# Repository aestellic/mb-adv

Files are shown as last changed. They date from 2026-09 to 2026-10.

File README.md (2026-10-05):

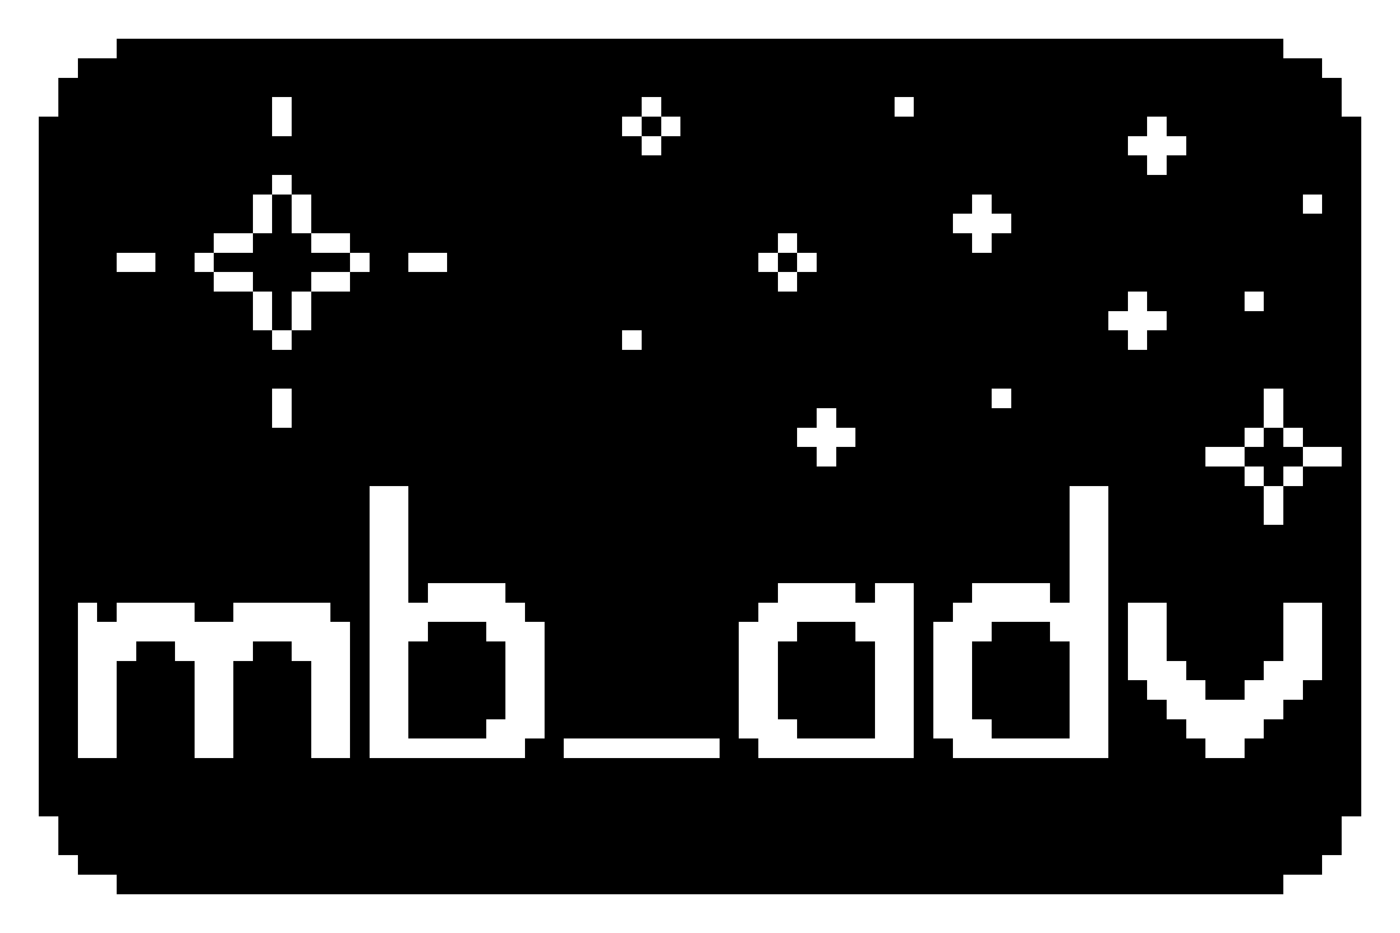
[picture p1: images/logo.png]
# 

> [!WARNING]
> This project (and its associated firmware) is a work-in-progress and is currently incomplete.

The mb_adv is a dongle for your GBA which injects multiboot ROMs via link cable.

With it, you can do stuff like [shiny hunt Jirachi without being tethered to a Gamecube](https://bsky.app/profile/cozydelaney.standingintheodds.com/post/3mt42ccd4bk23), boot [Poké Transporter GB](https://github.com/Striaton-Lab-Team/Poke_Transporter_GB), and even [connect your GBA to the internet](https://gblink.io/)!

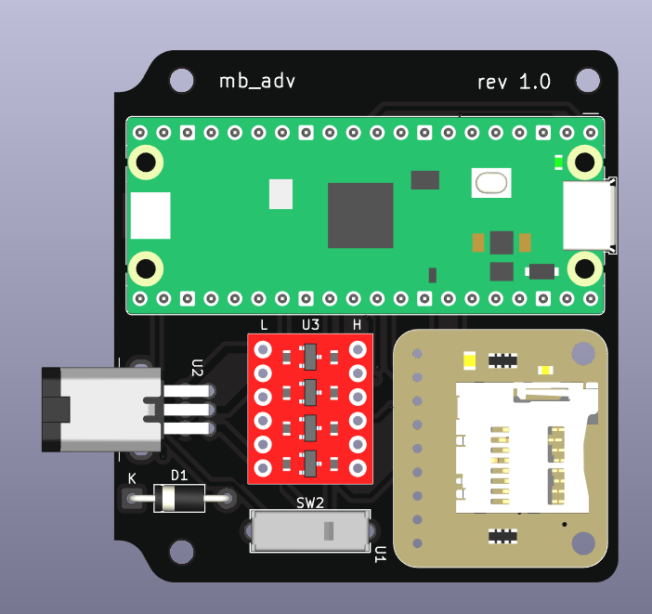
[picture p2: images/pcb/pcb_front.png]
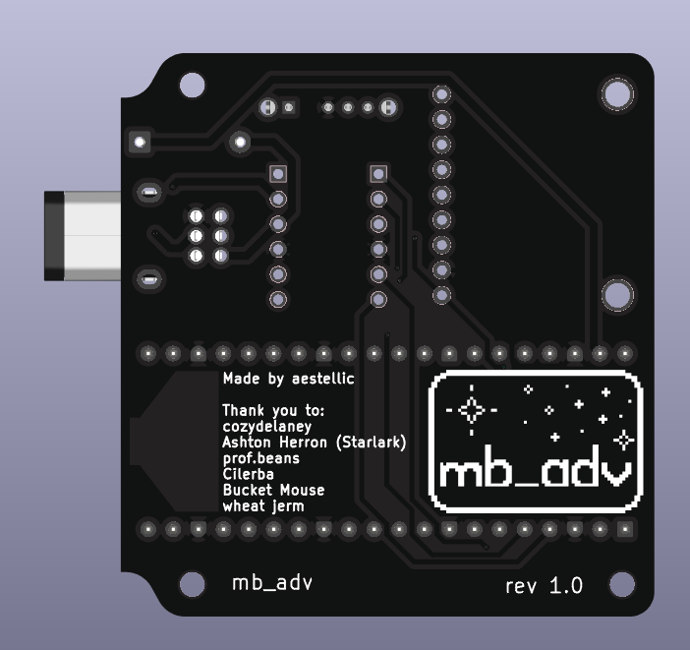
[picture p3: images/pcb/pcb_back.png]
 

If you'd like to buy one and are located in the USA, you can visit my store here (link will be added when store goes live). Otherwise, please see [MANUFACTURING.md](MANUFACTURING.md) for how to build one yourself!

# Usage
W.I.P

# F.A.Q.
How does this differ from the GB-Link?

- While the GB-Link needs to be connected to a computer/phone to work, the mb_adv draws power directly from the GBA. This lets the mb_adv work without plugging into any external devices!

What does mb_adv stand for?

- It stands for multiboot advance.

What the heck is a multiboot?

- It's a small GBA program that can be sent over the link cable. This is the same system that multiplayer games which only required one cartridge use. It's also used for a lot of Pokémon distributions!

How did you make this?

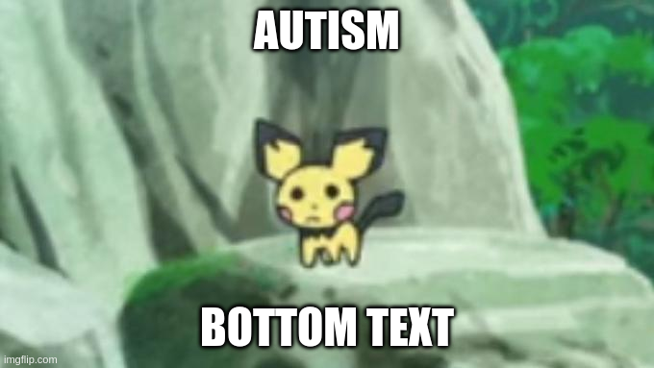
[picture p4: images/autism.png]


# Credits
This project would not have been possible without the following people:
- [cozydelaney](https://bsky.app/profile/cozydelaney.standingintheodds.com), who designed the logo and provided so much emotional support <3
- [Ashton Herron (Starlark)](https://github.com/starlarkus), who guided me through the planning stages of the mb_adv.
- [prof.beans](https://www.thebeanlabs.com/), who designed the enclosure for the mb_adv.
- [Bucket Mouse](https://github.com/MouseBiteLabs), who helped with choosing components and designing the schematic and PCB.
- wheat jerm, who helped with designing the schematic and PCB.
- [The GB-Link Team](https://gblink.io/), who created the incredible GB-Link and [GB-Link firmware](https://github.com/GB-Link/GBLink-Firmware).
- [loopj](https://github.com/loopj/gba-link-port), who created the footprint and 3D model for the male GBA link cable connector.
- [zaksabeast](https://github.com/zaksabeast/Portable-Pico-Multibooter), who served as the inspiration and foundation for this project
> Note: the mb_adv is not endorsed by zaksabeast in any way, shape, or form.

# License
This project is fully open sourced under the [MIT License](LICENSE).

# Technical References
See [MANUFACTURING.md](MANUFACTURING.md) and [SCHEMATIC.pdf](SCHEMATIC.pdf)

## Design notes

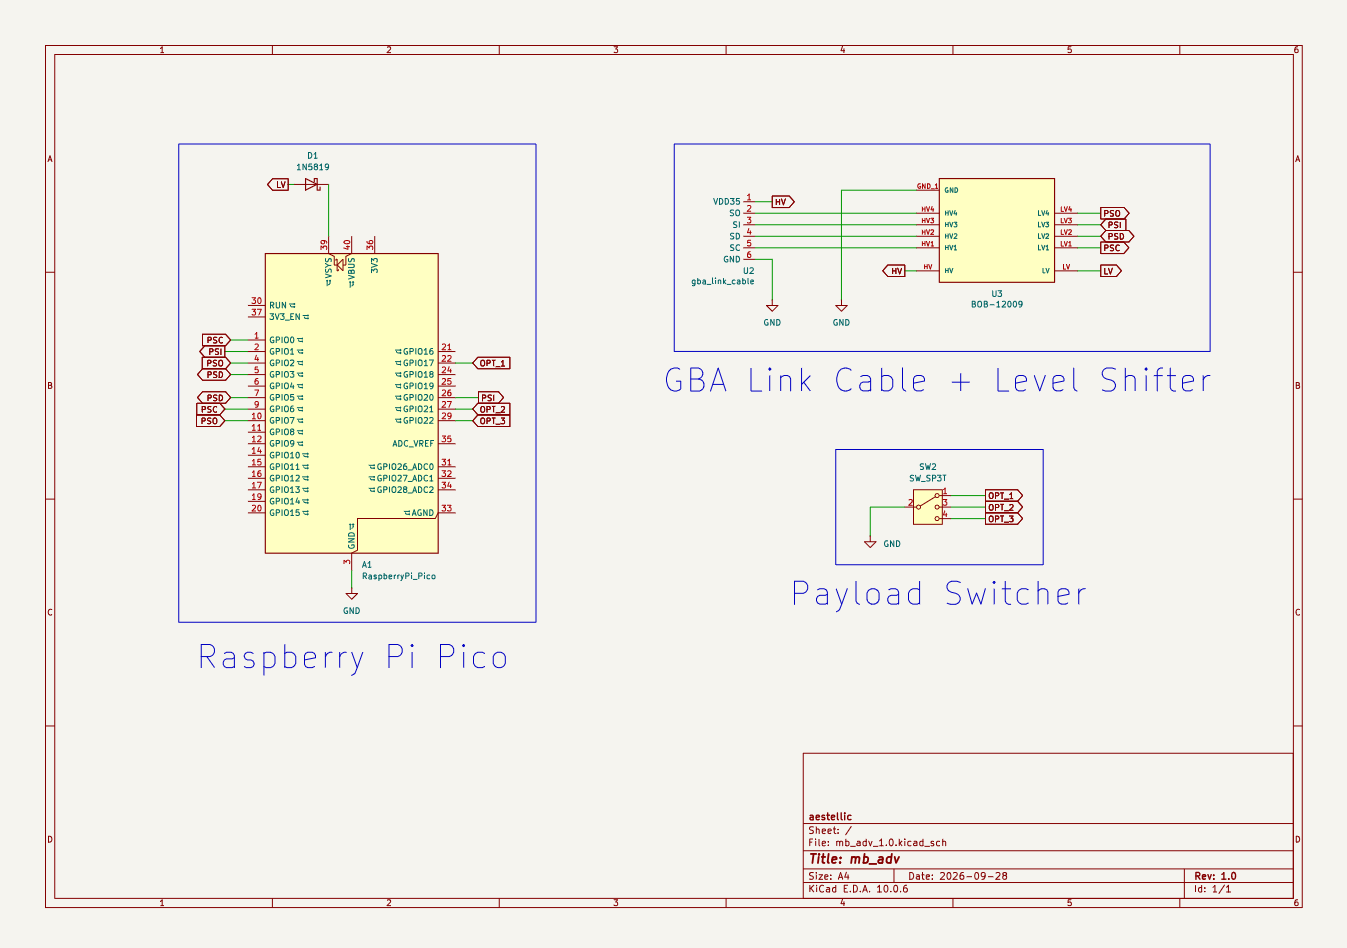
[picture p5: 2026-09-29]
images/pcb/schematic.png

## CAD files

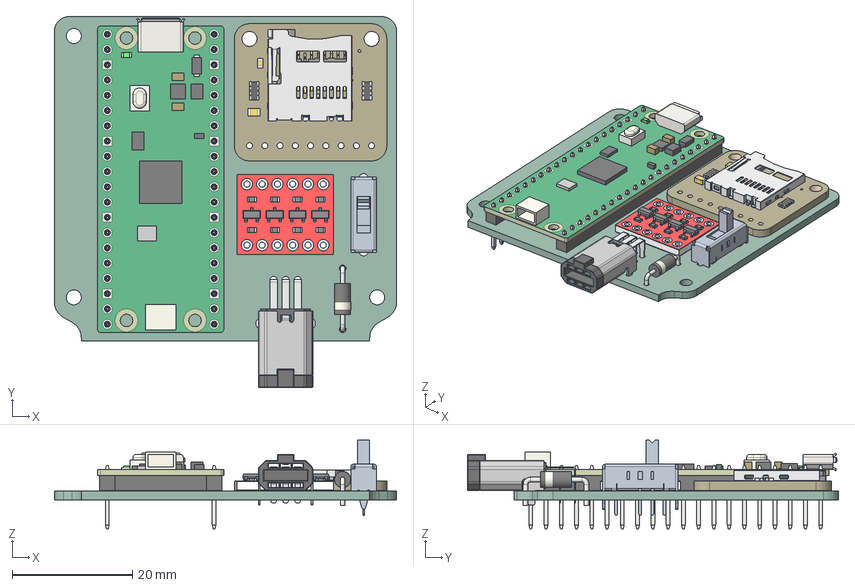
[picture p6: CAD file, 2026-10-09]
mb_adv_1.0.step
57.0 x 61.8 x 14.8 mm
Board
MICROSD
0805-NO
0603-NO
RESPACK_4X0603 x 2
Plastic Insert
Pin Long x 3
Pin Short x 3
BOB-12009
OS-103011MS8QP1_SW0001_PRT
D_DO-41_SOD81_P10.16mm_Horizontal
RaspberryPi_Pico_H_Module_KiCad
RaspberryPi_Pico_Header_DIP-40_H2.54mm_KiCad
mb_adv_1.0_PCB

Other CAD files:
mb_adv_1.0.stl

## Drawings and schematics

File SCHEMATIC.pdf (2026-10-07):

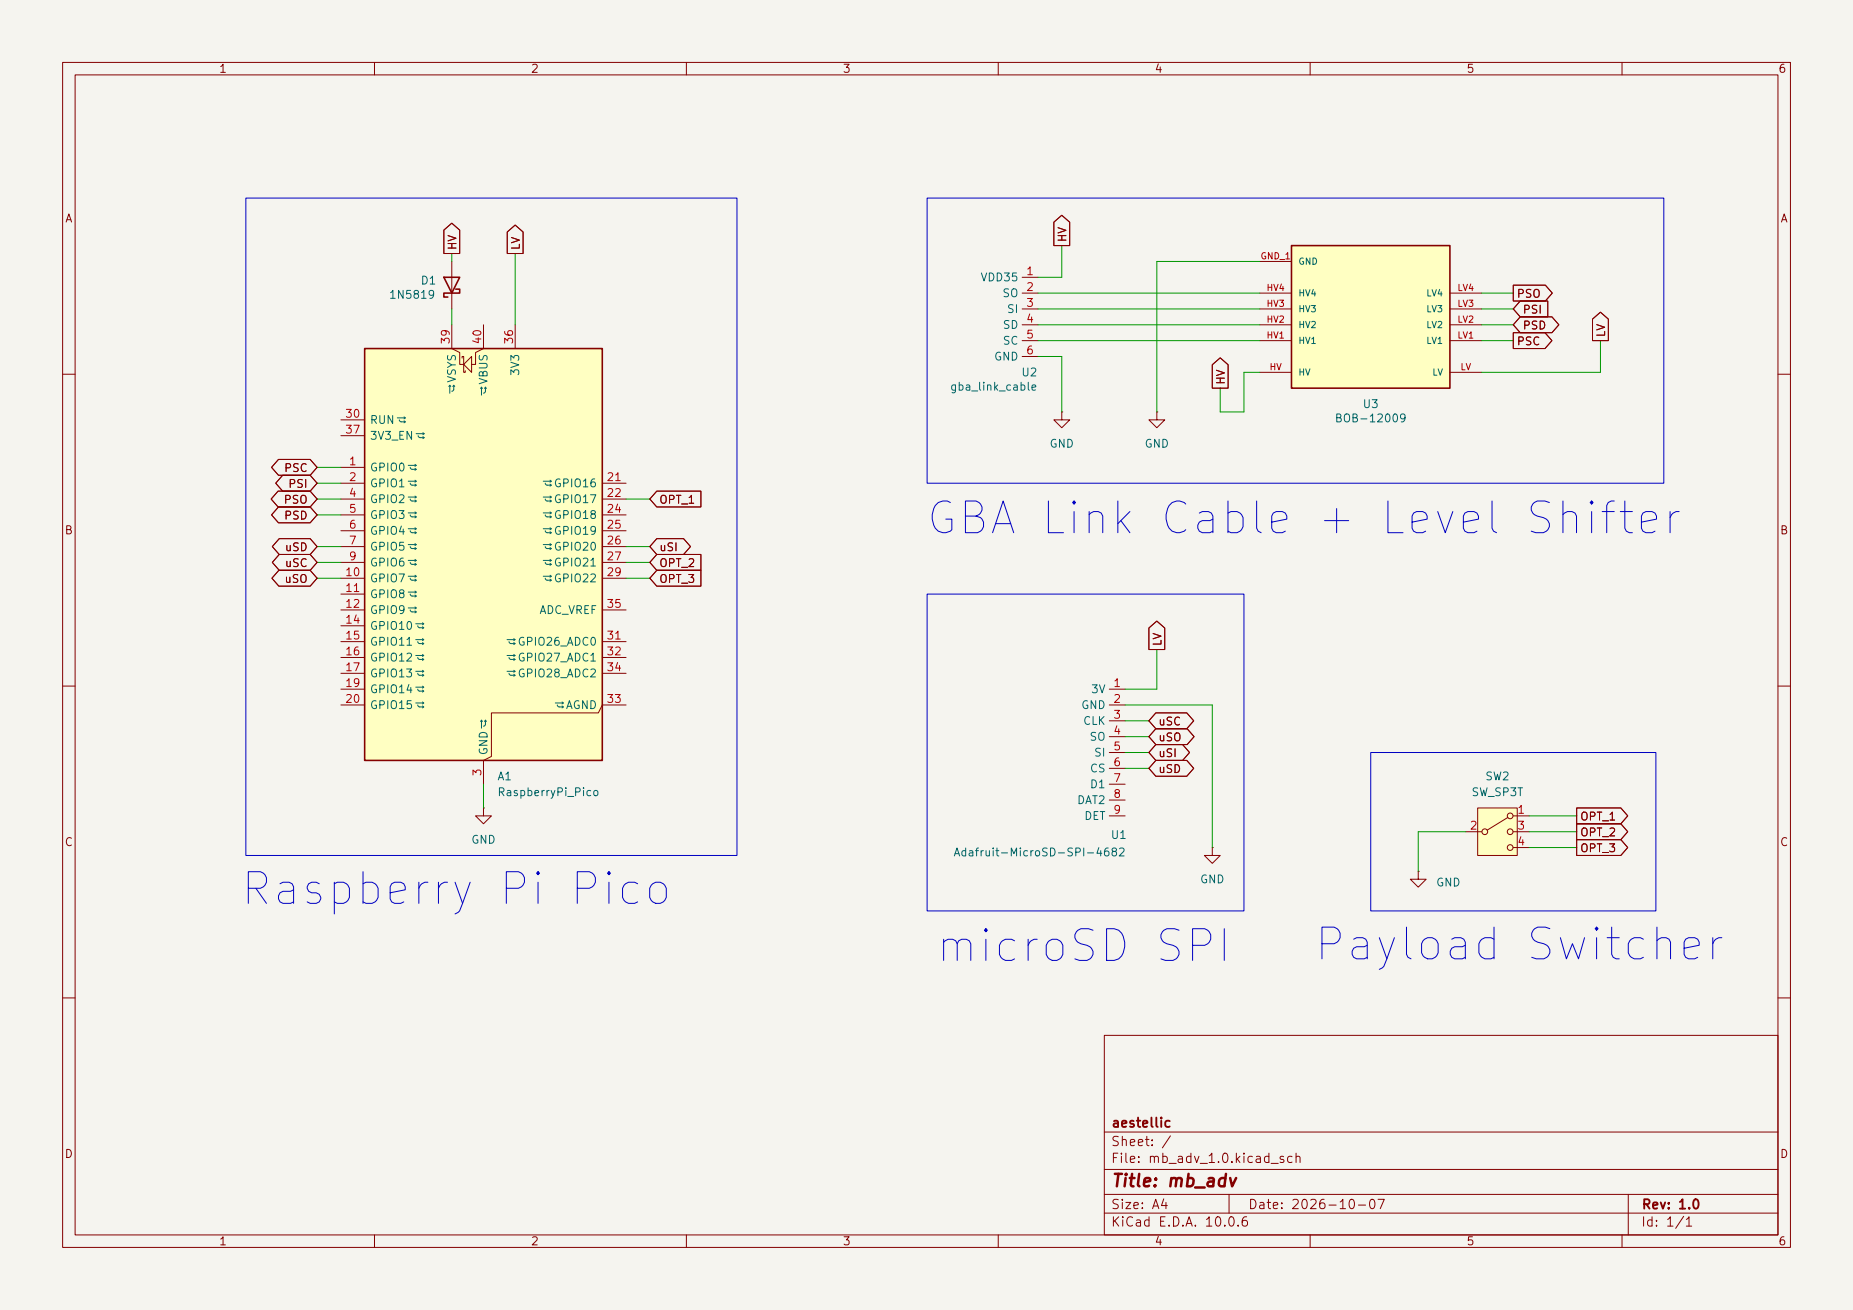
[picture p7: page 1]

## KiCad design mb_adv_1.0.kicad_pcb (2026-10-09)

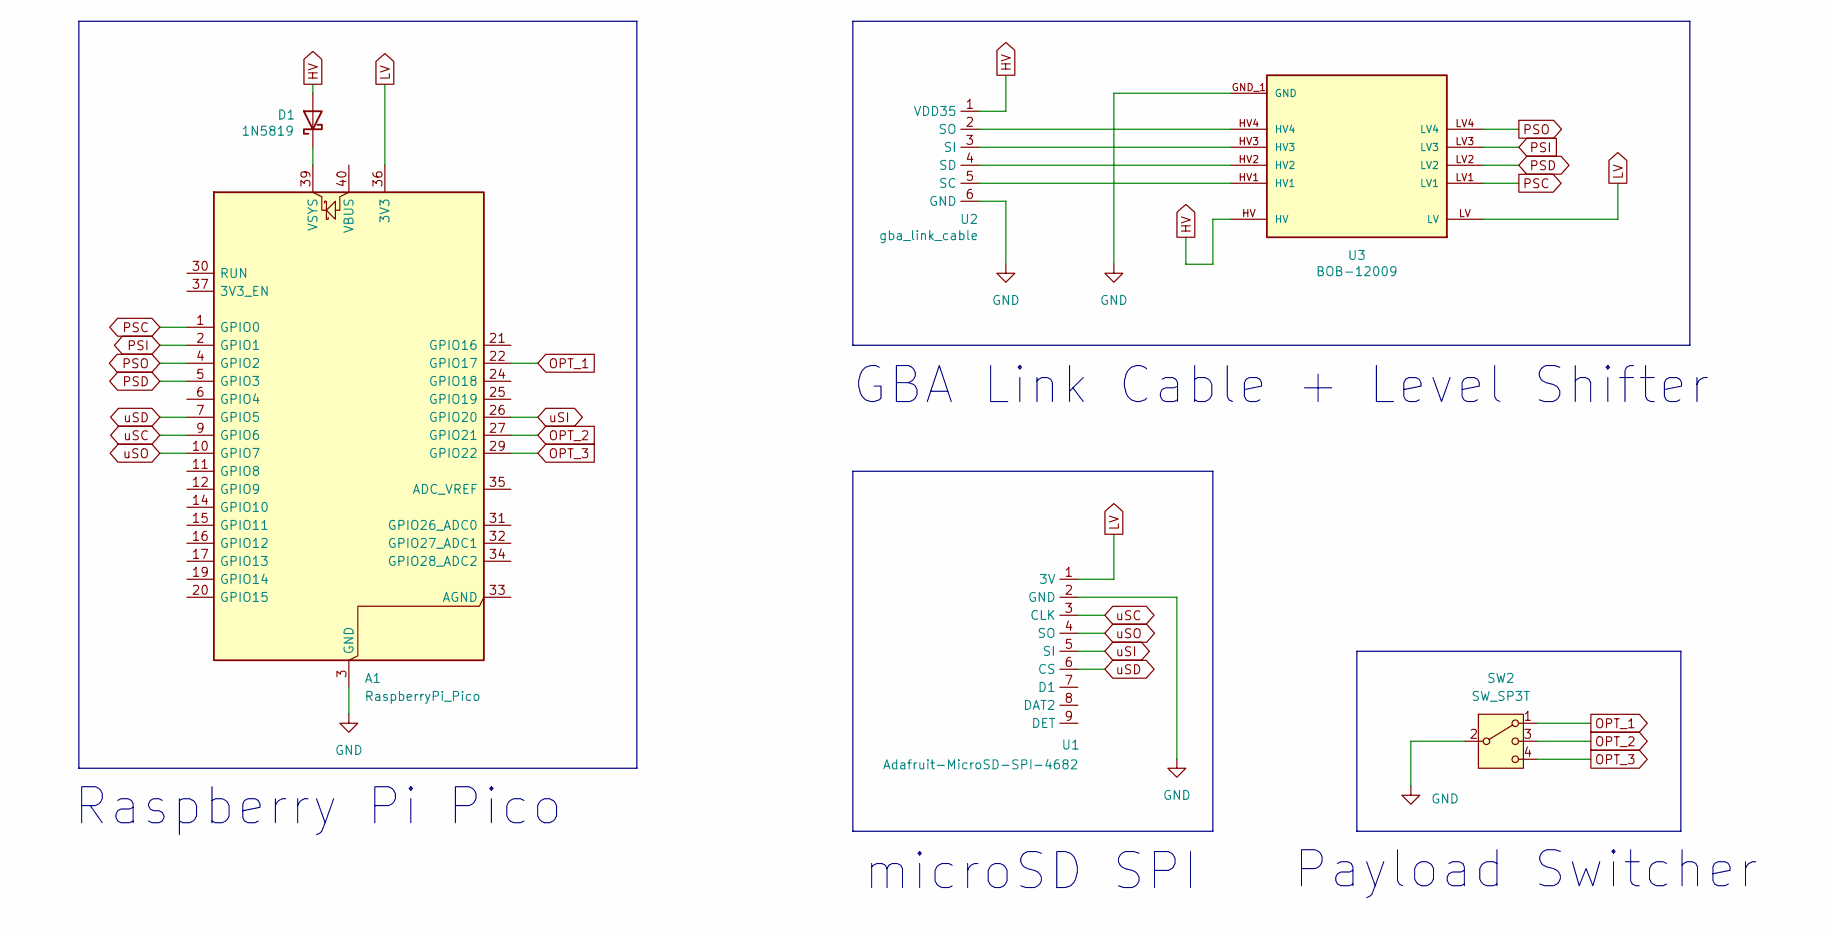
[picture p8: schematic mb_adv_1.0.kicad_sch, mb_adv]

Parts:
A1: RaspberryPi_Pico; RaspberryPi_Pico_Common_THT
D1: 1N5819; D_DO-41_SOD81_P10.16mm_Horizontal
SW2: SW_SP3T; DIP4_SP3T-TOP_4P3X8P6_CNK; MPN OS103011MS8QP1
U1: Adafruit-MicroSD-SPI-4682; adafruit_4682
U2: gba_link_cable; GBALinkPort_Male
U3: BOB-12009; CONV_BOB-12009; PARTREV 01

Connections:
GND: A1.3 (GND), A1.8 (GND), A1.13 (GND), A1.18 (GND), A1.23 (GND), A1.28 (GND), A1.38 (GND), SW2.2, U1.2 (GND), U2.6 (GND), U3.GND_1 (GND), U3.GND_2 (GND)
HV: D1.2 (A), U2.1 (VDD35), U3.HV
LV: A1.36 (3V3), U1.1 (3V), U3.LV
unnamed: A1.39 (VSYS), D1.1 (K)
unnamed: U2.5 (SC), U3.HV1
unnamed: U2.4 (SD), U3.HV2
unnamed: U2.3 (SI), U3.HV3
unnamed: U2.2 (SO), U3.HV4
OPT_1: A1.22 (GPIO17), SW2.1
OPT_2: A1.27 (GPIO21), SW2.3
OPT_3: A1.29 (GPIO22), SW2.4
PSC: A1.1 (GPIO0), U3.LV1
PSD: A1.5 (GPIO3), U3.LV2
PSI: A1.2 (GPIO1), U3.LV3
PSO: A1.4 (GPIO2), U3.LV4
uSC: A1.9 (GPIO6), U1.3 (CLK)
uSD: A1.7 (GPIO5), U1.6 (CS)
uSI: A1.26 (GPIO20), U1.5 (SI)
uSO: A1.10 (GPIO7), U1.4 (SO)

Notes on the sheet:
GBA Link Cable + Level Shifter
Payload Switcher
microSD SPI
Raspberry Pi Pico

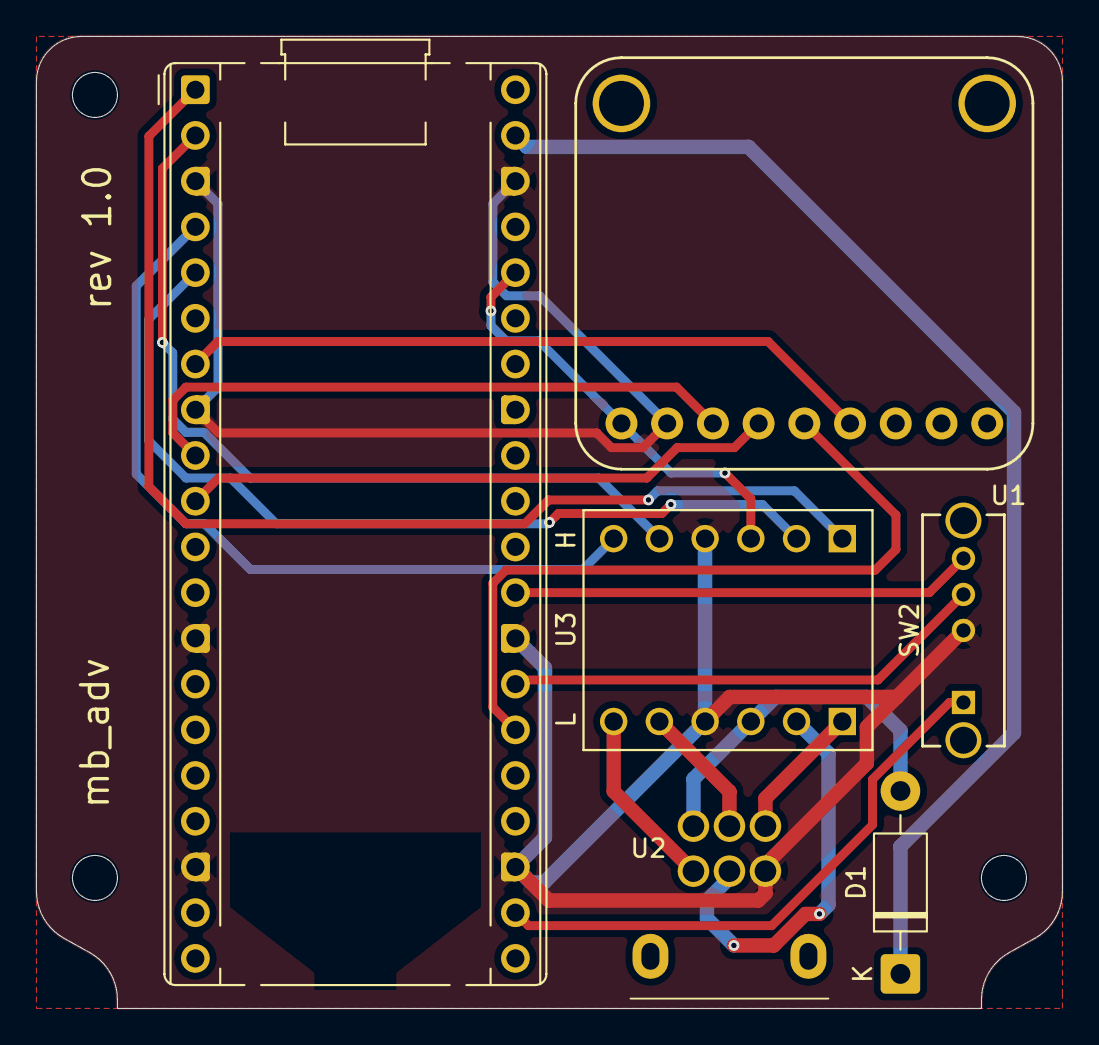
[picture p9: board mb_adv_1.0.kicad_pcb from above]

Board: 2 copper layers, 57.0 x 54.0 mm, 9 parts (0 on the bottom side), 19 nets.

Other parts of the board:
M2.5, M2.5#2, M2.5#3: MountingHole_2.5mm

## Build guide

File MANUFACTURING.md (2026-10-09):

# Manufacturing
### This is done at your own risk. I am neither suggesting nor recommending that you do this.
### These instructions do not contain any affiliate links.
1. Download GERBERS.zip
2. Go to your PCB fabricator of choice (i.e. [JLCPCB](https://cart.jlcpcb.com/quote)) and order however many PCBs you wish to make using the following settings:

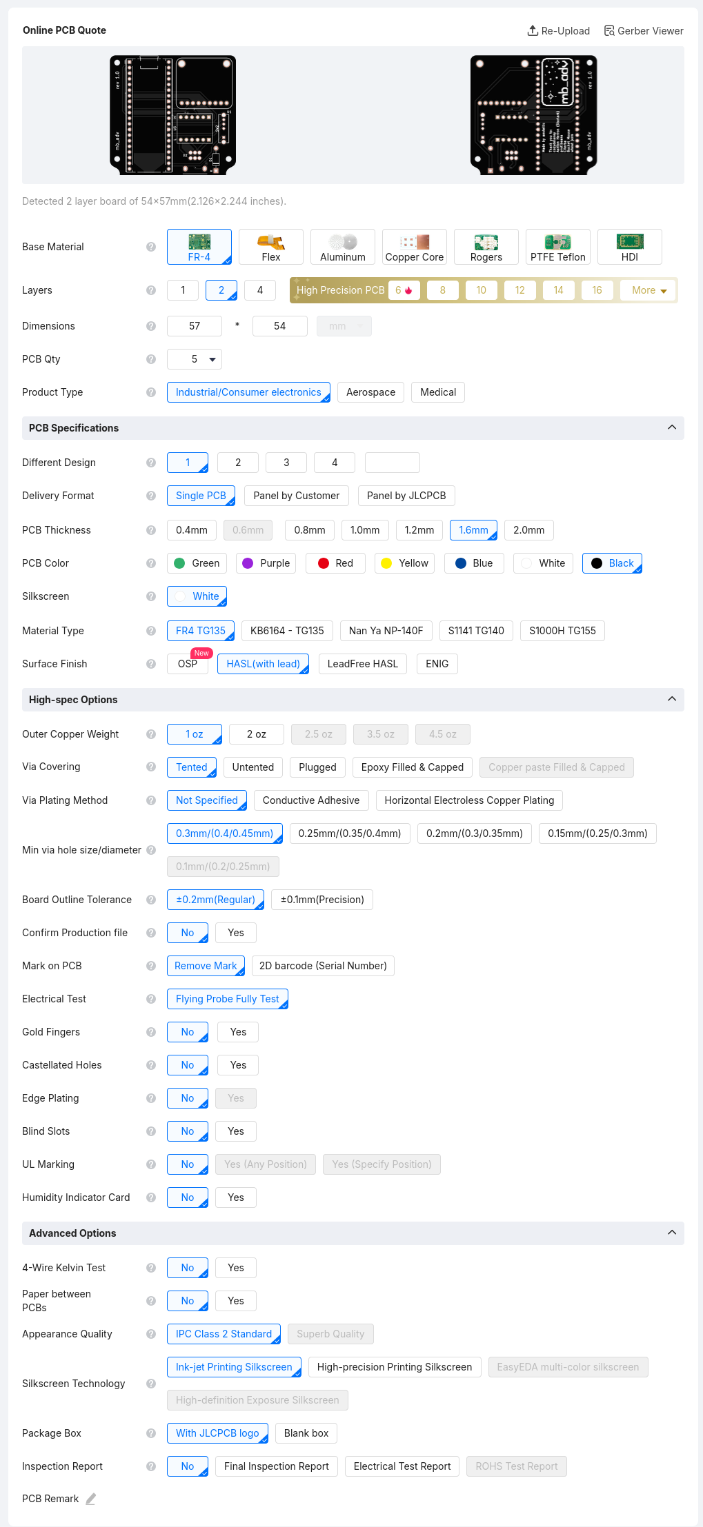
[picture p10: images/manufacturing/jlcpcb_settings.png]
JLCPCB settings


3. Choose your preferred shipping option by clicking the down arrow
> Note: JLCPCB uses ~$30 USD shippping by default. Global Standard Direct Line costs ~$7 USD and there haven't been any reports of people actually being charged the tariff in the US to my knowledge.

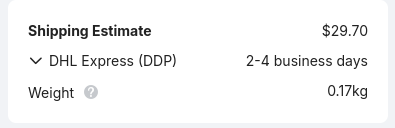
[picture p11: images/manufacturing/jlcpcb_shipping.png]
JLCPCB shipping


3.5. If you don't have access to a 3D printer, you may want to jump to step 7. Most PCB fabricators also offer 3D printing services.

4. Place your PCB (and optionally 3D printed case) order.

5. Order the following components (one per mb_adv):

|Name|Part #|Link|Notes|
|---|---|---|---|
|Raspberry Pi Pico|N/A|[4MB](https://www.aliexpress.us/item/3256808040042288.html)|Any 2MB+ Pico (including clones) which follows the official footprint is compatible with the PCB, but the buttons may not line up with the 3d printed case contained in this repo.|
|Through Hole Diode|1N5819|[DigiKey](https://www.digikey.com/short/rqfn3zbq)|Link will automatically add 1N5819, OS103011MS8QP1, 12009, and 4682 to your DigiKey cart|
|SP3T Switch|OS103011MS8QP1|[DigiKey](https://www.digikey.com/short/rqfn3zbq)|Link will automatically add 1N5819, OS103011MS8QP1, 12009, and 4682 to your DigiKey cart|
|Logic Level Shifter|12009|[DigiKey](https://www.digikey.com/short/rqfn3zbq)|Link will automatically add 1N5819, OS103011MS8QP1, 12009, and 4682 to your DigiKey cart|
|MicroSD SPI|4682|[DigiKey](https://www.digikey.com/short/rqfn3zbq)|Link will automatically add 1N5819, OS103011MS8QP1, 12009, and 4682 to your DigiKey cart|
|GBA Male Link Port|N/A|[Alibaba](https://www.alibaba.com/product-detail/6Pin-90-Degree-Curved-Feet-Male_1601634644553.html)|N/A|

6. Once everything arrives, solder the components onto the PCB.
> Note: If you are not comfortable soldering, you can bring the components, PCB, and a this guide to your local electronics repair shop and they could probably do it for you.

7. 3D print the case (link will be added once it has been designed)

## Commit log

2026-09-27 Organize repo
    [BOM.csv, mb_adv_1.0.kicad_pcb]
2026-09-28 update README.md, schematic, and pcb
    [mb_adv_1.0.kicad_pcb, mb_adv_1.0.kicad_sch]
2026-09-29 update pinout
    [mb_adv_1.0.kicad_pcb, mb_adv_1.0.kicad_sch]
2026-09-30 update pcb rev
    [mb_adv_1.0.kicad_pcb]
2026-10-05 embed step models
    [mb_adv_1.0.kicad_pcb]
2026-10-07 add microSD card
    [BOM.csv, mb_adv_1.0.kicad_pcb, mb_adv_1.0.kicad_sch]
2026-10-09 finalize PCB
    [mb_adv_1.0.kicad_pcb, mb_adv_1.0.step, mb_adv_1.0.stl]
